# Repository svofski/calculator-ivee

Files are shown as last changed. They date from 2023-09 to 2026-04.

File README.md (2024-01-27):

# Design files for IVEE Forth-based calculator

The original is here: https://github.com/zooxo/iv ( [Youtube demo](https://www.youtube.com/watch?v=m1aFRhqvuLM) )

Expectation:



Reality:

[Youtube video of IVEE](https://www.youtube.com/watch?v=LmGt2pndoQI)

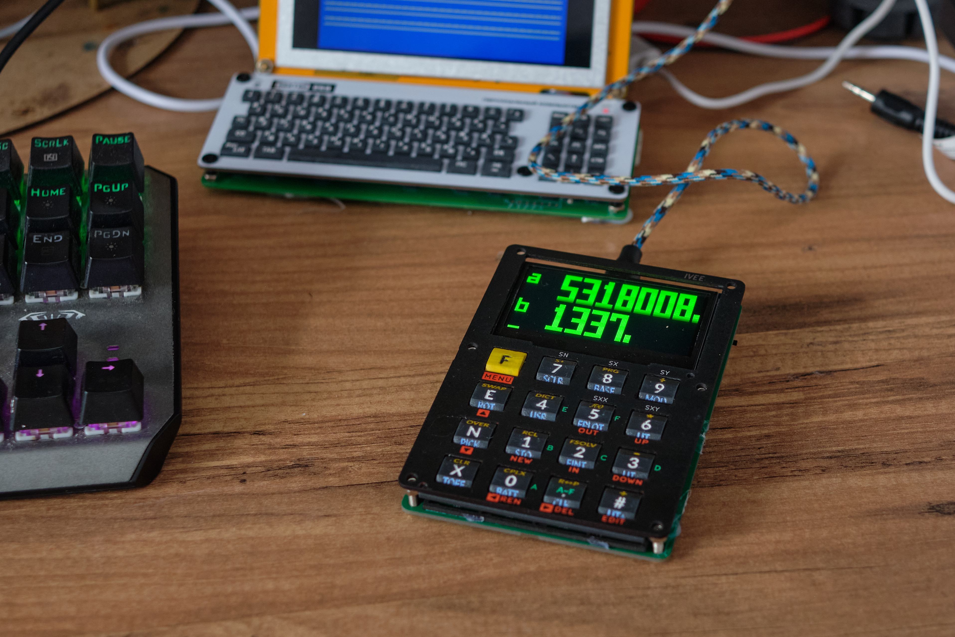
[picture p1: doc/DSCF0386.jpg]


### KiCad project

[Open in kicanvas.org](https://kicanvas.org/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)

### Parts reference:

OLED 2.42 inch https://aliexpress.com/item/32950307344.html

switches SKRRAAE010 https://aliexpress.com/item/1005004917288663.html

on/off switch MSK-12C02 https://aliexpress.com/item/4000685483225.html

### Other

Battery shared load circuits:

 * https://forum.arduino.cc/t/proper-usage-of-lithium-charger-based-on-tp4056/477206/2
 * https://forum.arduino.cc/t/powering-a-pro-micro-board-with-li-ion-battery-and-usb-connector/572981/3

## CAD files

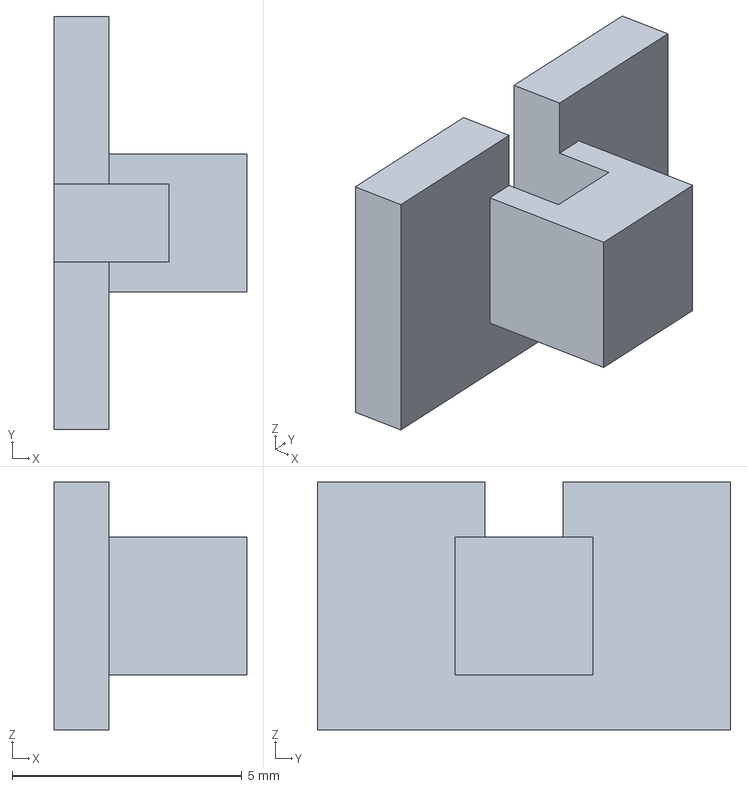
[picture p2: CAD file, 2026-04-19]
cad/pipa.FCStd
4.20 x 9.00 x 5.40 mm

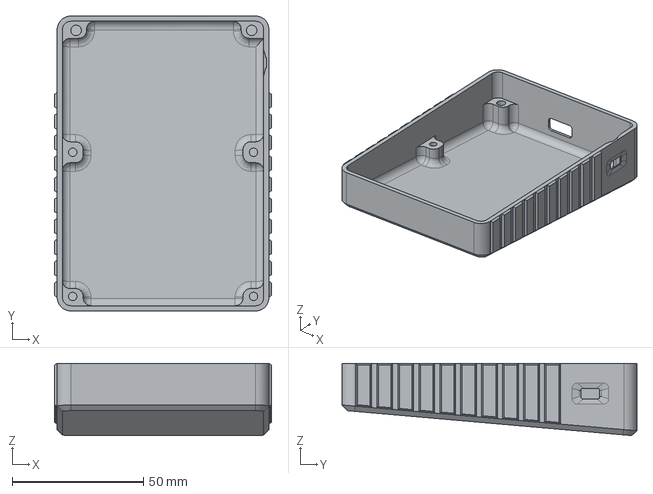
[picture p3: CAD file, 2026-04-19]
cad/case-Tushka.step
82.8 x 112.6 x 27.5 mm

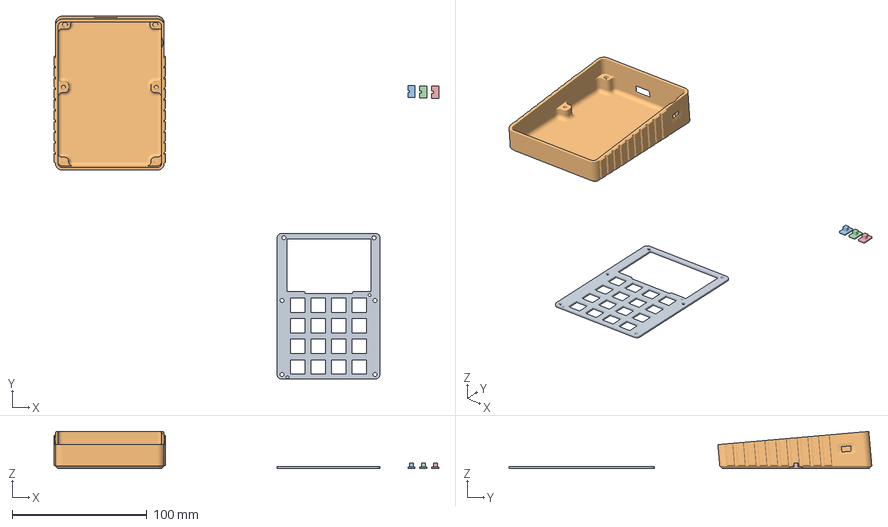
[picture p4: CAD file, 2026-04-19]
cad/case.3mf
285.8 x 269.3 x 27.6 mm
calc-top-face.step
case-Tushka.step
case-pipa.step x 3

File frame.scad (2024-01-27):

//
// (Hopefully) printable key frame to be used with dome switches
//

$fn=32;

unit = 2.54;
eps = 0.01;
wall = 1;

cover_thicc = 1.6;

pitch = 6;    // button pitch in units
base = 4;     // button side in units

button_inside_h = 0.6;
pcb_h = 1.6;
button_yofs = 0.6;    // height of the dome switch
gap = 0.3;
pushrod_r = 0.9;  // central push rod
pushrod_h = 0.4;  // push rod length

spring_h = 0.8;

button_base_h = button_inside_h + pcb_h;
cage_height = button_yofs + spring_h + pushrod_h;

nkeys_x = 4;
nkeys_y = 4;

module singlecage(sx=pitch, sy=pitch, height=cage_height)
{
    width = sx * unit;
    depth = sy * unit;

    difference() {
        cube([width, depth, height]);

        translate([wall * 0.5, wall * 0.5,-eps])
            cube([width - wall, depth - wall, height + wall]);
    }
}

module outercage()
{
  width = unit * pitch * nkeys_x;
  depth = unit * pitch * nkeys_y;
  translate([-wall, -wall, 0])
    difference() {
      cube([width + 2 * wall, depth + 2 * wall, cage_height]);
      translate([wall, wall, -eps]) cube([width, depth, cage_height + 2 * eps]);
    }

  cylinder(h=cage_height + pcb_h, r = 0.6);
  translate([width, depth, 0])
      cylinder(h=cage_height + pcb_h, r = 0.6);
}

module cagehole()
{
    sz = base * unit + 2 * gap;
    ofs = (unit * pitch - sz) / 2;

    translate([wall, wall, 0])
    translate([ofs,ofs,-eps]) cube([sz, sz, 10]);
}

module coverplate()
{
  width = unit * pitch * nkeys_x;
  depth = unit * pitch * nkeys_y;
  translate([-wall, -wall, cage_height + 0.1])
    difference() {
        cube([width + 2 * wall, depth + 2 * wall, cover_thicc]);

        union() {
            for (y = [0:nkeys_y - 1]) translate([0, y * unit * pitch, 0]) 
            {
                for (x = [0:nkeys_x - 1]) translate([x * unit * pitch, 0, 0])
                {
                    cagehole();
                }
            }
        }
    }
}


module button(sx=base, sy=base, base_h=button_base_h, top_h1=2, top_h2=1, withbottom=1)
{
    width = sx * unit;
    depth = sy * unit;
    depth2 = (sy - 2) * unit;

    if (withbottom)
    {
        // pushrod
        translate([width/2, depth/2, 0]) cylinder(r = pushrod_r, h = pushrod_h);
    }

    intersection()  {
      union() {
          // base
          if (withbottom) {
              translate([0, 0, pushrod_h]) cube([width, depth, base_h]);
          }

          width2 = width - 0.25;

          // prism
          translate([0, 0, base_h + pushrod_h])
              hull() {
                  // prism bottom
                  cube([width, depth, eps]);
                  // prism top
                  translate([(width - width2)/2, (depth - depth2)/2 - 0.25, top_h1]) 
                      cube([width2, depth2, eps]);
                  // back slope should be almost flat
                  translate([0, depth-eps, 0]) cube([width, eps, top_h1 - top_h2]);
              }
      }

      translate([width/2, depth/2, 0]) cylinder(r = width/2 * sqrt(1.9), h = 5);

    }
}

// squiggly springs: unprintable at this scale
module spring()
{
    hull() {
        cylinder(r=wall/2, h=spring_h);
        translate([unit, unit/2, 0]) 
            cylinder(r=wall/2, h=spring_h);
    }
    hull() {
        translate([0, unit, 0]) 
            cylinder(r=wall/2, h=spring_h);
        translate([unit, unit/2, 0]) 
            cylinder(r=wall/2, h=spring_h);
    }
}

module spring2()
{
    translate([0, 0, button_yofs + pushrod_h]) 
    {
        translate([unit*1.2, wall/4, 0])
        {
            spring();
        }

        translate([pitch * unit - unit*1.2, pitch * unit - wall/4, 0])
        {
            scale([-1, -1, 1]) spring();
        }
    }
}

module squiggly_springs()
{
    spring2();
    translate([unit * pitch / 2, unit * pitch/2, 0])
        rotate([0, 0, 90]) 
        translate([-unit * pitch / 2, -unit * pitch/2, 0]) spring2();
}

// leaf springs: need to be made thicker than usable for printability
// they will have to be cut down to be thinner in post
module leaf_springs()
{
    width = unit * 2;
    depth = unit * 2;

    // the finger should be 0.8 mm high (better less), but jlcpcb requires 1.5 min
    // this will have to be filed down
    height = 1.55;     

    translate([unit * pitch / 2 - width/2, unit * pitch - depth + wall/2, button_yofs + pushrod_h])
        cube([width, depth, height]);
}

module cagebutton()
{
    singlecage();
    translate([unit * (pitch - base) / 2, unit * (pitch - base) / 2, button_yofs])
        button();

    //squiggly_springs();
    leaf_springs();
}

module allkeys()
{
    for (y = [0:nkeys_y - 1]) translate([0, y * unit * pitch, 0]) 
    {
        for (x = [0:nkeys_x - 1]) translate([x * unit * pitch, 0, 0])
        {
            cagebutton();
        }
    }
}

allkeys();
outercage();
//coverplate();

emboss_depth=1;
module buttontop()
{
    translate([unit * (pitch - base) / 2, unit * (pitch - base) / 2, button_yofs])
    difference() {
        translate([0,0,eps]) button(withbottom=0);
        scale([2, 1.01, 1]) translate([-1, -0.005, -emboss_depth]) button(withbottom=0);
    }
}

module buttontops()
{
    for (y = [0:nkeys_y - 1]) translate([0, y * unit * pitch, 0]) 
    {
        for (x = [0:nkeys_x - 1]) translate([x * unit * pitch, 0, 0])
        {
            buttontop();
        }
    }
}

// this is insanely slow and produces buggy meshes anyway
//module emboss()
//{
//    color([1,0,1])
//        translate([0,0,0.1]) {
//            intersection() {
//                buttontops();
//                //linear_extrude(15) import("botones-emboss.svg");
//                import("text-stl.stl");
//            }
//        }
//}

//emboss();
//difference() {
//  allkeys();
//  emboss();
//}

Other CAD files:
cad/case2.FCStd
cad/case-pipa.step

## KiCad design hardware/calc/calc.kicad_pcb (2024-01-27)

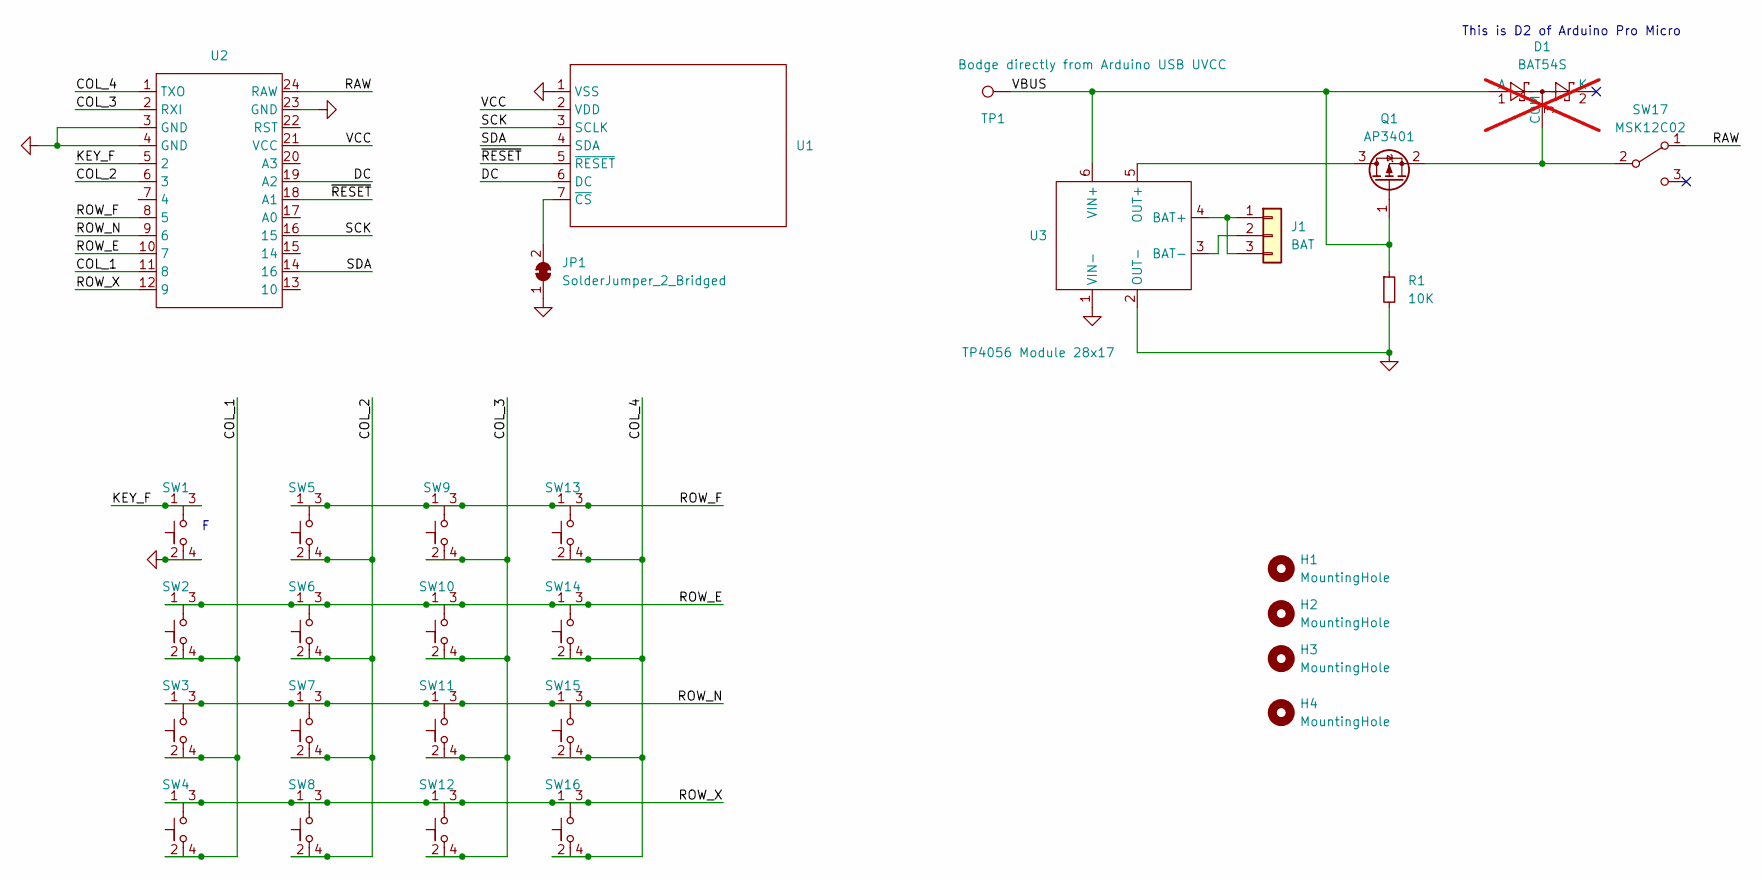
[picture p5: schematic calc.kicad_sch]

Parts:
D1: BAT54S; SOT-23; not fitted
H1, H2, H3, H4: MountingHole; MountingHole_3.2mm_M3
J1: BAT; PinHeader_1x03_P2.54mm_Vertical
JP1: SolderJumper_2_Bridged; SolderJumper-2_P1.3mm_Bridged_Pad1.0x1.5mm
Q1: AP3401; SOT-23
R1: 10K; R_0805_2012Metric
SW1, SW2, SW3, SW4, SW5, SW6, SW7, SW8, SW9, SW10, SW11, SW12, SW13, SW14, SW15, SW16: SKRRAAE010-15.24mm-keyboard-pitch
SW17: MSK12C02
TP1: Bodge directly from Arduino USB UVCC; TestPoint_THTPad_2.0x2.0mm_Drill1.0mm
U1: OLED_2.42inch_SPI_7PIN
U2: Arduino Pro Micro USB-C 36.8x17.7
U3: TP4056 Module 28x17

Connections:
/COL_1: SW2.2, SW2.4, SW3.2, SW3.4, SW4.2, SW4.4, U2.11 (8)
/COL_2: SW5.2, SW5.4, SW6.2, SW6.4, SW7.2, SW7.4, SW8.2, SW8.4, U2.6 (3)
/COL_3: SW9.2, SW9.4, SW10.2, SW10.4, SW11.2, SW11.4, SW12.2, SW12.4, U2.2 (RXI)
/COL_4: SW13.2, SW13.4, SW14.2, SW14.4, SW15.2, SW15.4, SW16.2, SW16.4, U2.1 (TXO)
/DC: U1.6 (DC), U2.19 (A2)
/KEY_F: SW1.1, SW1.3, U2.5 (2)
/RAW: SW17.1 (A), U2.24 (RAW)
/ROW_E: SW2.1, SW2.3, SW6.1, SW6.3, SW10.1, SW10.3, SW14.1, SW14.3, U2.10 (7)
/ROW_F: SW5.1, SW5.3, SW9.1, SW9.3, SW13.1, SW13.3, U2.8 (5)
/ROW_N: SW3.1, SW3.3, SW7.1, SW7.3, SW11.1, SW11.3, SW15.1, SW15.3, U2.9 (6)
/ROW_X: SW4.1, SW4.3, SW8.1, SW8.3, SW12.1, SW12.3, SW16.1, SW16.3, U2.12 (9)
/SCK: U1.3 (SCLK), U2.16 (15)
/SDA: U1.4 (SDA), U2.14 (16)
/VBUS: D1.1 (A), Q1.1 (G), R1.1, TP1.1, U3.6 (VIN+)
/VCC: U1.2 (VDD), U2.21 (VCC)
/~RESET: U1.5 (~RESET), U2.18 (A1)
GND: JP1.1 (A), R1.2, SW1.2, SW1.4, U1.1 (VSS), U2.3 (GND), U2.4 (GND), U2.23 (GND), U3.1 (VIN-), U3.2 (OUT-)
unnamed: D1.3 (COM), Q1.2 (S), SW17.2 (B)
unnamed: J1.1, J1.3, U3.4 (BAT+)
unnamed: J1.2, U3.3 (BAT-)
unnamed: JP1.2 (B), U1.7 (~CS)
unnamed: Q1.3 (D), U3.5 (OUT+)

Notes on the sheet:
This is D2 of Arduino Pro Micro

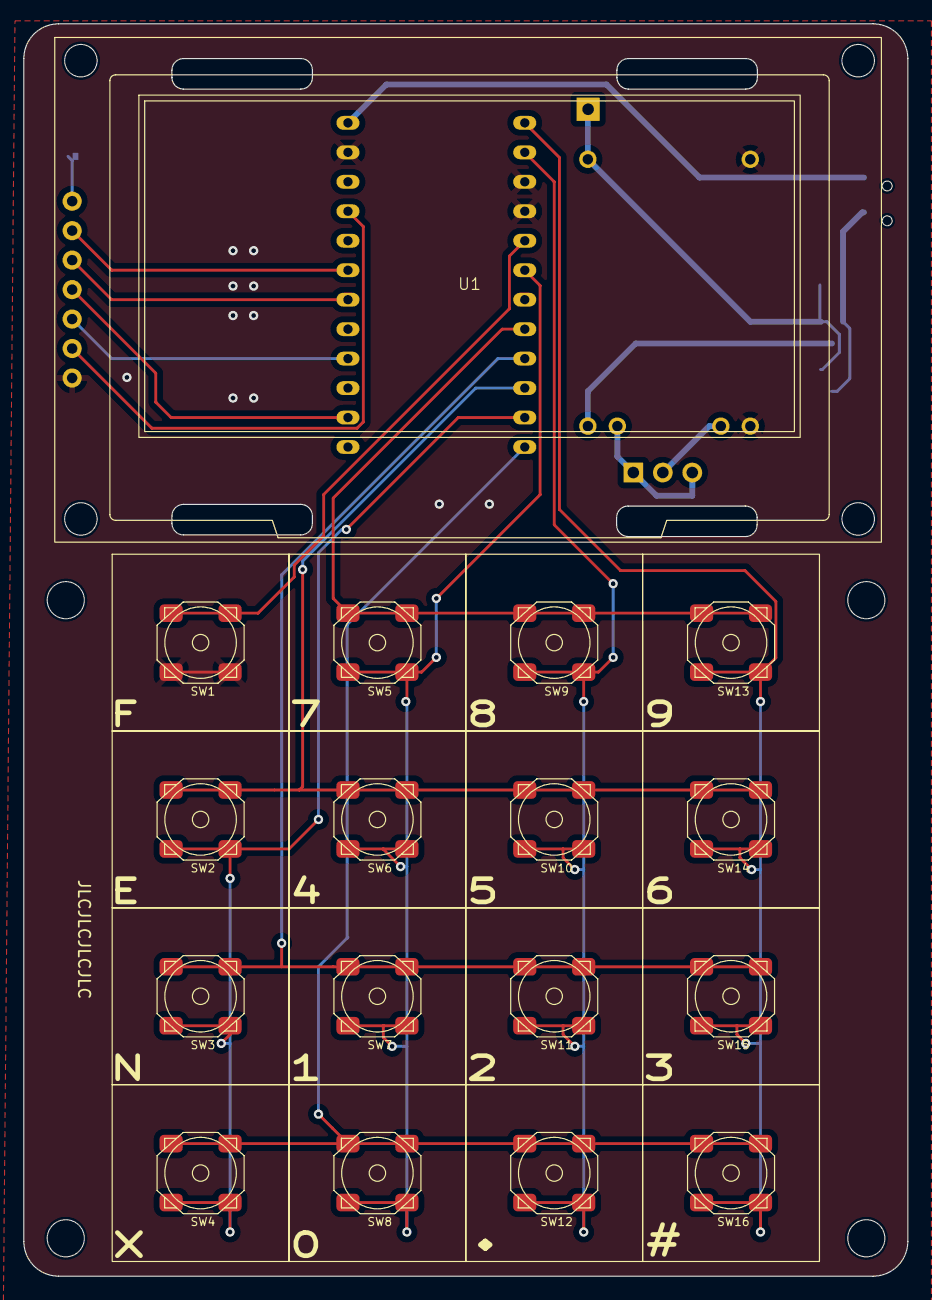
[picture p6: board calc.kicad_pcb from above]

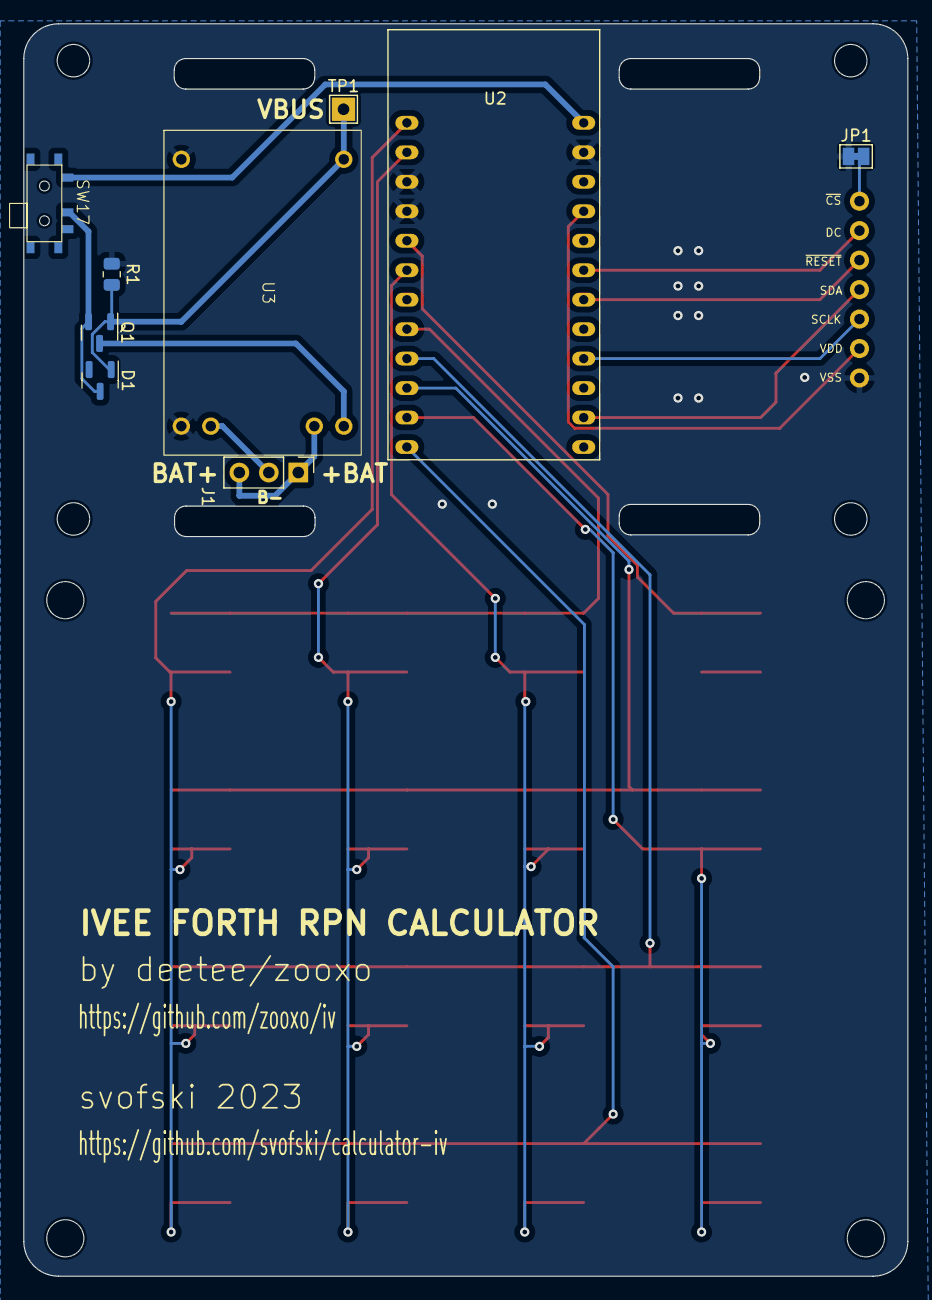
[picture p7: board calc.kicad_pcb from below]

Board: 2 copper layers, 76.2 x 107.9 mm, 30 parts (9 on the bottom side), 22 nets.

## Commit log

2024-01-27 updated kicad files
    [calc.kicad_pcb, calc.kicad_sch, frame.scad]
2026-04-19 3dprintering files
    [case-Tushka.step, case-pipa.step, case.3mf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]
